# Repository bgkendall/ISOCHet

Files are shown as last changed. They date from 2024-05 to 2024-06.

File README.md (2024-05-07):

# ISOCHět

Macro pad based around an ISO Enter and using the CH552E MCU.

## Prerequisites

 * KiCad v7.0.9 or later
 * The following KiCad plugins are used for keyboard-specific components:
   * [marbastlib](https://github.com/ebastler/marbastlib) — footprints
   * [Keyswitch Kicad Library](https://github.com/kiswitch/kiswitch) —  3D models
 * [Josefin Sans](https://github.com/googlefonts/josefinsans) font — used for PCB text
 * FreeCAD v0.21.2 or later

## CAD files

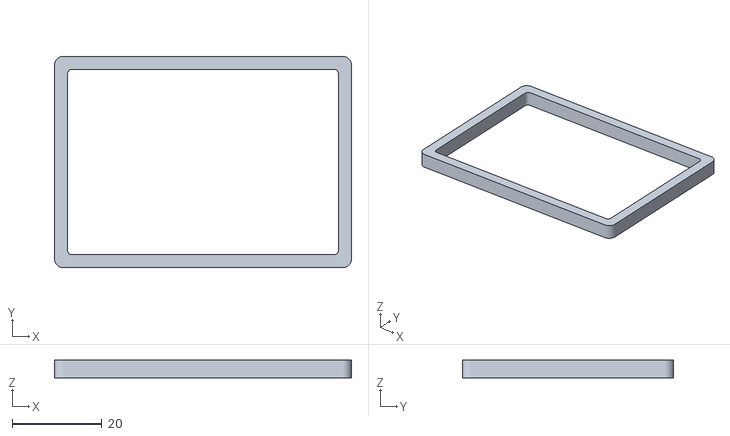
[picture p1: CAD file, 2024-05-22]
Case/ISOCHet-Accent.stl
66.2 x 47.1 x 4.00

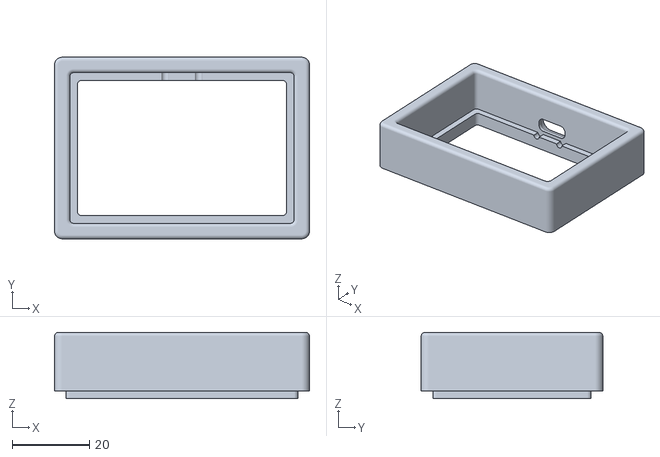
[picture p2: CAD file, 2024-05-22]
Case/ISOCHet-Body.stl
66.2 x 47.1 x 17.2

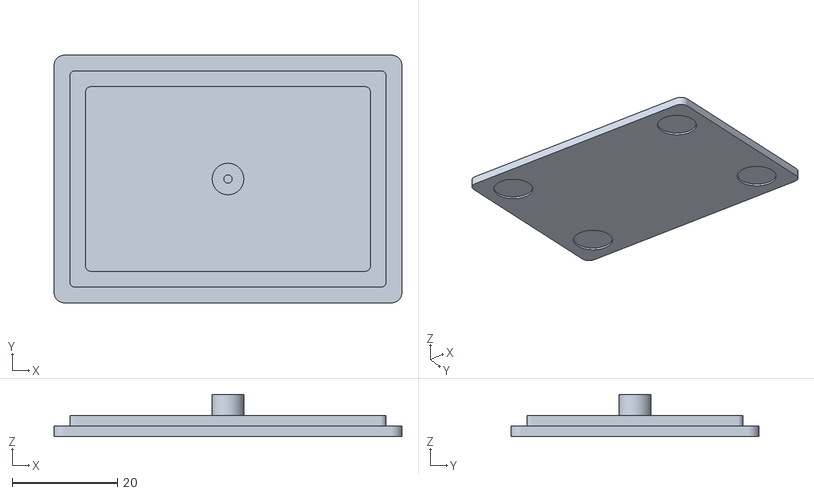
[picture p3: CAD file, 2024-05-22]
Case/ISOCHet-Base.stl
66.2 x 47.1 x 8.00

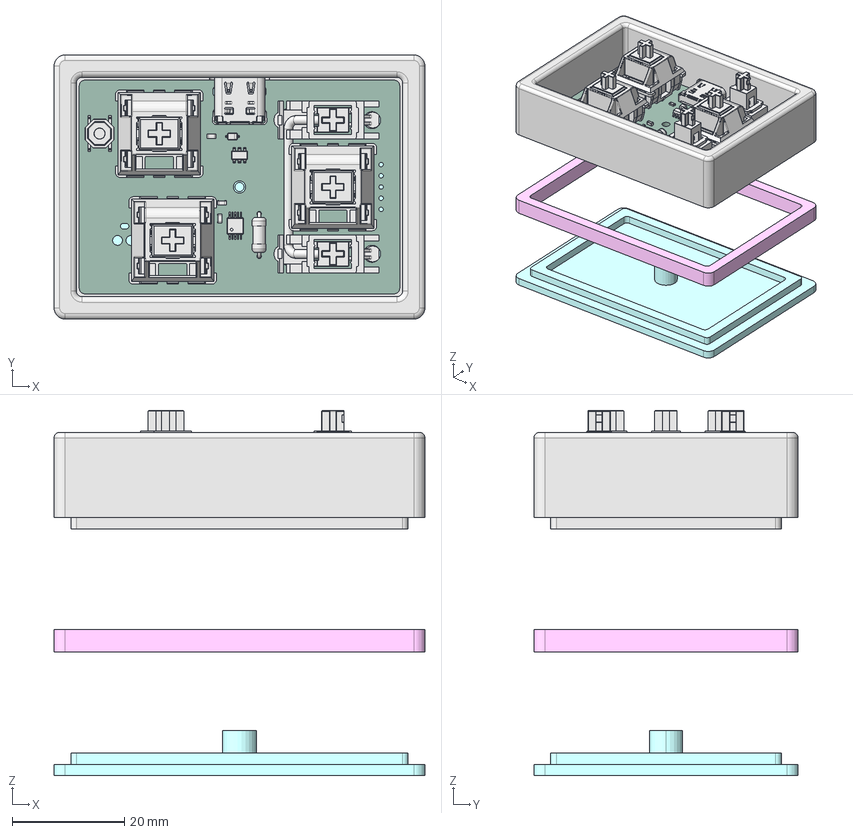
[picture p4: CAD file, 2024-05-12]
Case/ISOCHet.FCStd
66.2 x 47.1 x 65.1 mm
Base
Accent
ISOCHet PCB

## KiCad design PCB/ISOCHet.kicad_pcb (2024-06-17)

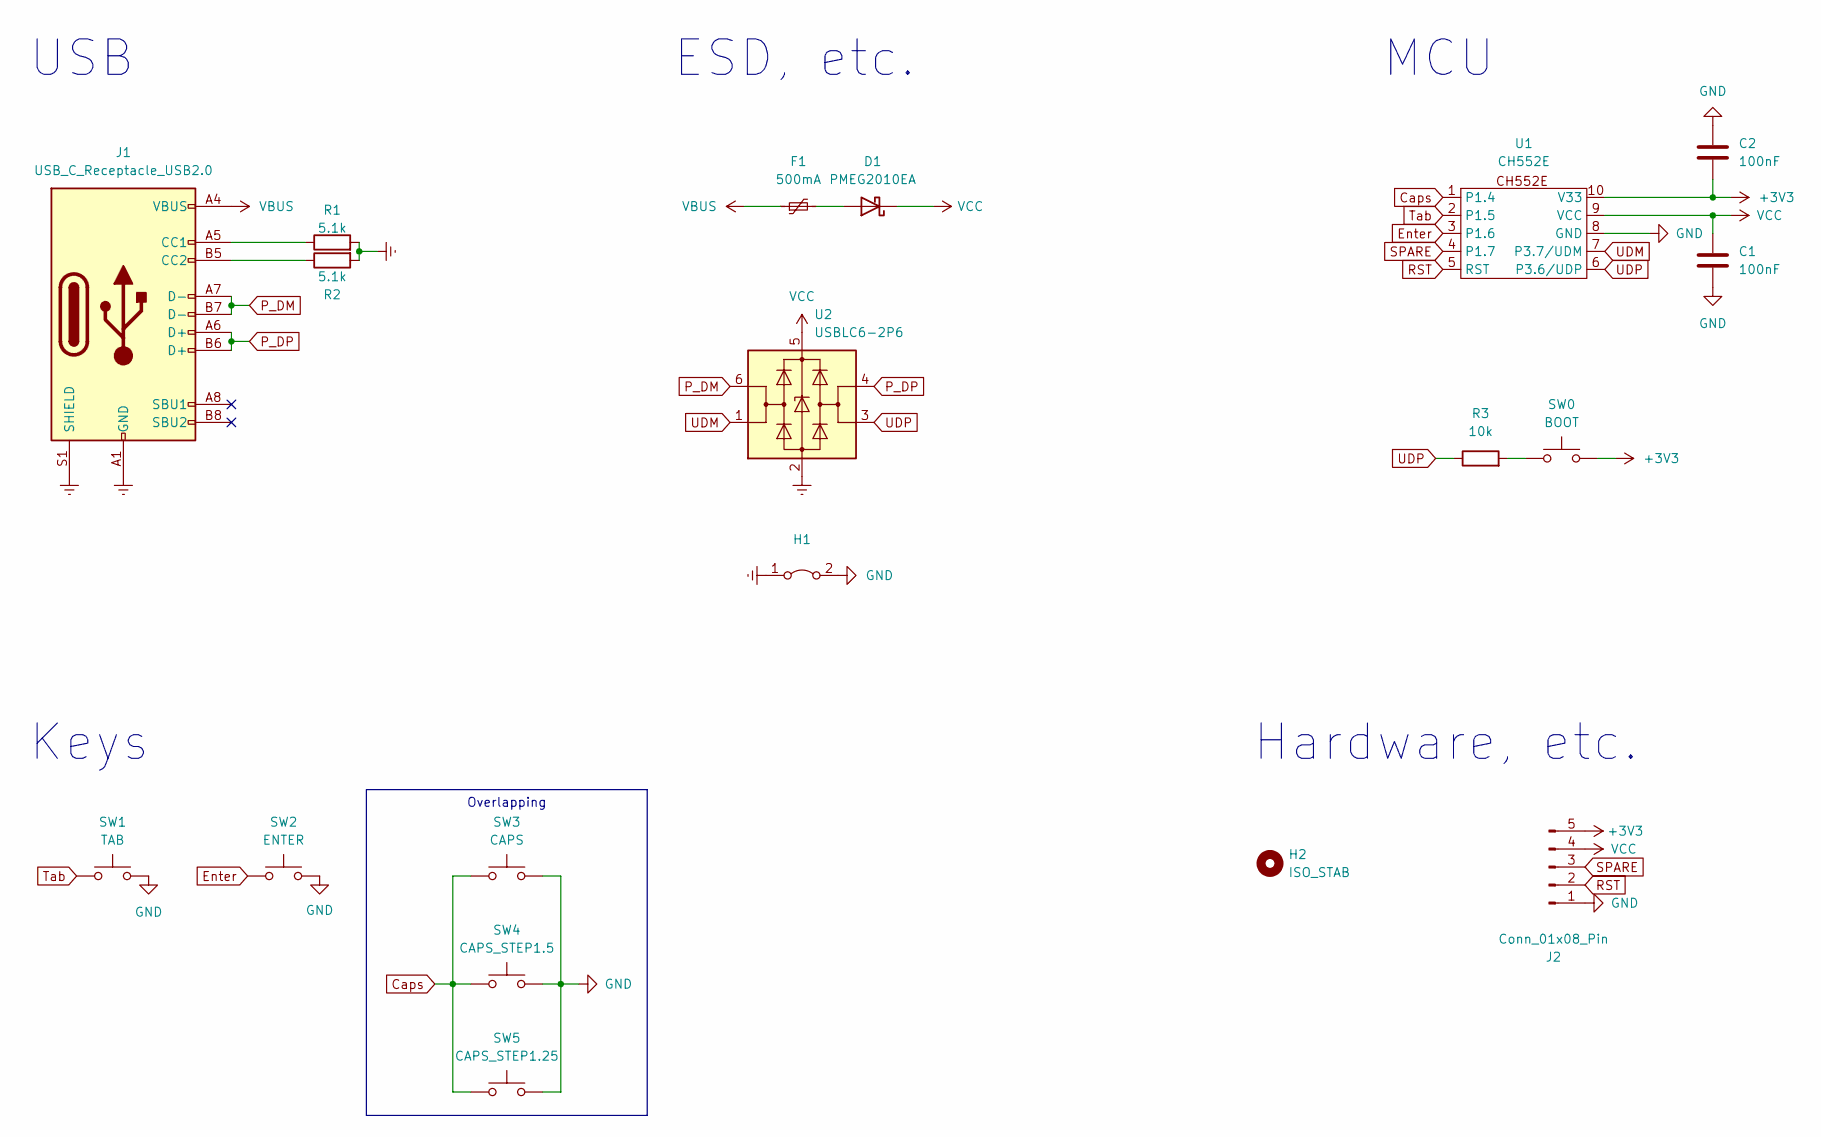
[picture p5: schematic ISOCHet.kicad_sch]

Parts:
C1, C2: 100nF; C_0603_1608Metric_Pad1.08x0.95mm_HandSolder; LCSC C66501
D1: PMEG2010EA; D_SOD-323_HandSoldering; LCSC C2837790
F1: 500mA; Fuse_0603_1608Metric_Pad1.05x0.95mm_HandSolder; LCSC C210357
H1: Mounting Hole/Isolated Ground Jumper; MountingHole_2.2mm_M2_DIN965_Pad_Isolated_Ground_Jumper
H2: ISO_STAB; STAB_MX_P_ISO-ROT
J1: USB_C_Receptacle_USB2.0; GSB1C211110DS1HR; LCSC C2840393
J2: Conn_01x08_Pin; PinHeader_1x05_P2.00mm_Vertical
R1, R2: 5.1k; R_0603_1608Metric_Pad0.98x0.95mm_HandSolder; LCSC C23186
R3: 10k; R_Combined_DIN0207_1608; LCSC C25804
SW0: BOOT; SW_SPST_SKQG_WithStem; LCSC C115351
SW1: TAB; SW_MX_1.5u
SW2: ENTER; SW_MX_1u
SW3: CAPS; SW_MX_1.75u
SW4: CAPS_STEP1.5; SW_MX_1.75u_STP_1.5
SW5: CAPS_STEP1.25; SW_MX_1.75u_STP_1.25
U1: CH552E; MSOP-10_3x3mm_P0.5mm; LCSC C967938
U2: USBLC6-2P6; SOT-23-6_Handsoldering; LCSC C2827654

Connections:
+3V3: C2.1, J2.5, SW0.2, U1.10 (V33)
Caps: SW3.1, SW4.1, SW5.1, U1.1 (P1.4)
Earth: H1.1 (A), J1.A1 (GND), J1.A12 (GND), J1.B1 (GND), J1.B12 (GND), J1.S1 (SHIELD), R1.2, R2.2, U2.2 (GND)
Enter: SW2.1, U1.3 (P1.6)
GND: C1.2, C2.2, H1.2 (B), J2.1, SW1.2, SW2.2, SW3.2, SW4.2, SW5.2, U1.8 (GND)
unnamed: D1.2 (A), F1.2
unnamed: J1.A5 (CC1), R1.1
unnamed: J1.B5 (CC2), R2.1
unnamed: R3.2, SW0.1
P_DM: J1.A7 (D-), J1.B7 (D-), U2.6 (I/O1)
P_DP: J1.A6 (D+), J1.B6 (D+), U2.4 (I/O2)
RST: J2.2, U1.5 (RST)
SPARE: J2.3, U1.4 (P1.7)
Tab: SW1.1, U1.2 (P1.5)
UDM: U1.7 (P3.7/UDM), U2.1 (I/O1)
UDP: R3.1, U1.6 (P3.6/UDP), U2.3 (I/O2)
VBUS: F1.1, J1.A4 (VBUS), J1.A9 (VBUS), J1.B4 (VBUS), J1.B9 (VBUS)
VCC: C1.1, D1.1 (K), J2.4, U1.9 (VCC), U2.5 (VBUS)

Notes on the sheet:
Overlapping
Keys
MCU
Hardware, etc.
ESD, etc.
USB

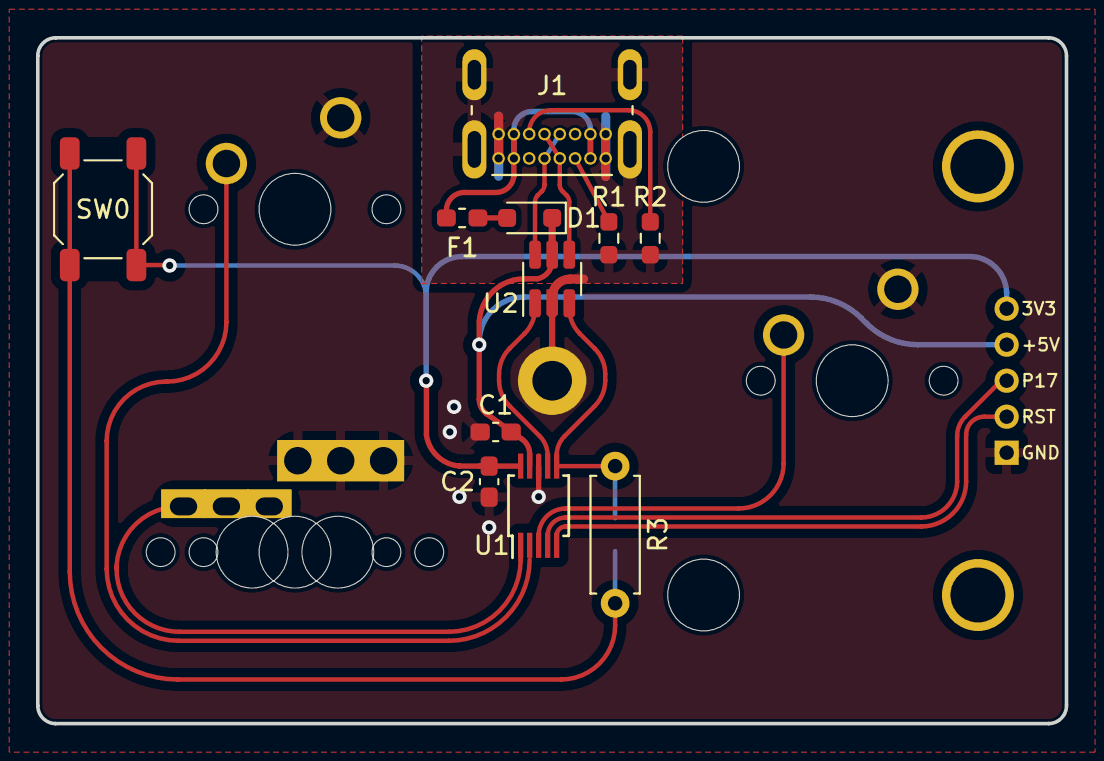
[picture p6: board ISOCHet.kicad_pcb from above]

Board: 2 copper layers, 57.1 x 38.1 mm, 19 parts (1 on the bottom side), 18 nets.

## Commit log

2024-04-16 Add first version of ISOCHet PCB
    [ISOCHet.kicad_pcb, ISOCHet.kicad_sch]
2024-04-16 Flip USB port to top side; add 3D models
    [ISOCHet.kicad_pcb, ISOCHet.kicad_sch]
2024-04-17 Add LSCC part numbers; add 3D models for MX switches and stabiliser
    [ISOCHet.kicad_pcb, ISOCHet.kicad_sch]
2024-04-17 Move OSHW logo to front, PCB name, etc. to back, and straighten a few traces
    [ISOCHet.kicad_pcb]
2024-04-17 Swap R1 and R2
    There’s more room for the via on the other side of the USB port.
    [ISOCHet.kicad_pcb]
2024-04-21 Rotate ISO stabiliser, improve STEP export
    [ISOCHet.kicad_pcb, ISOCHet.kicad_sch]
2024-04-21 Add first draft of case
    [ISOCHet.FCStd]
2024-04-21 Move CC resistors away from PCB edge
    [ISOCHet.kicad_pcb]
2024-04-21 Add cutouts for USB port solder
    [ISOCHet.FCStd]
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2024-04-21 Move components
    * Move decoupling capacitor C1 close to U1
    * Move U1 away from PCB edge
    * Align U1 with PCB centreline
    [ISOCHet.kicad_pcb, ISOCHet.kicad_sch]
2024-04-22 Use larger footprint for J2 header
    [ISOCHet.kicad_pcb, ISOCHet.kicad_sch]
2024-04-22 Update PCB model in case design
    [ISOCHet.FCStd]
2024-04-22 Tweak ESD routing
    [ISOCHet.kicad_pcb]
2024-04-23 Use Alps SKQG switch for BOOT, update LCSC part numbers, add DigiKey part numbers
    [ISOCHet.kicad_pcb, ISOCHet.kicad_sch]
2024-04-23 Change footprint for USB port
    USB C socket is now GSB1C211110DS1HR instead of GCT USB4085. Update routing with more filleting on 90° corners.
    [ISOCHet.kicad_pcb, ISOCHet.kicad_sch]
2024-04-23 Swap R1 and R2 (again)
    Also, make some routing prettier.
    [ISOCHet.kicad_pcb]
2024-04-25 Tidy up schematic
    [ISOCHet.kicad_sch]
2024-04-25 Refresh from schematic and tweak routing
    [ISOCHet.kicad_pcb]
2024-04-25 Rotated CH552 90° and rerouted accordingly
    [ISOCHet.kicad_pcb, ISOCHet.kicad_sch]
2024-04-26 Change routing of UDM and UDP
    Now leave U2 straight down rather than at 90°
    [ISOCHet.kicad_pcb]
2024-04-26 Tweak silkscreen lables for R3, C1 and C2
    [ISOCHet.kicad_pcb]
2024-04-26 Match width of pin-to-pin and thermal relief connections on Caps and J2
    [ISOCHet.kicad_pcb]
2024-04-26 Scooch order number
    [ISOCHet.kicad_pcb]
2024-04-26 Add courtyard for stabiliser screw pads
    [ISOCHet.kicad_pcb]
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2024-04-26 Tweak position of USB port, update PCB model in case design
    [ISOCHet.FCStd, ISOCHet.kicad_pcb]
2024-04-29 Create draft of version using CH552E
    [ISOCHet.kicad_pcb, ISOCHet.kicad_sch]
2024-05-02 Move all components to front
    USB data pins on port now line up with CH552E and do not need to crossover.
    R1 and R2 remain on back.
    Tweaked overlapping Caps Lock switch footprints to reduce DRC errors.
    Power tracks are now 0.3mm to match maximum width of CH552E pads.
    [ISOCHet.kicad_pcb, ISOCHet.kicad_sch]
2024-05-02 Use Josefin Sans for all mask text
    [ISOCHet.kicad_pcb]
2024-05-03 Prepare for production
    * Set fabrication flags.
    * Remove order number — cost is no different for a board this small.
    [ISOCHet.kicad_pcb]
2024-05-03 Isolate USD port ground from main PCB ground
    [ISOCHet.kicad_pcb]
2024-05-03 Move CC1 such that it is before U1, not after
    [ISOCHet.kicad_pcb]
2024-05-03 Round outside corners of keep-out areas
    KiCad only seems to round the inside corners, so some arcs on the GND net are added.
    [ISOCHet.kicad_pcb]
2024-05-03 Reroute UDP to Boot switch tracks
    [ISOCHet.kicad_pcb]
2024-05-03 Relocate and enlarge logo
    [ISOCHet.kicad_pcb]
2024-05-04 Switch USBLC6 (U2) to cheaper LCSC part number
    [ISOCHet.kicad_pcb, ISOCHet.kicad_sch]
2024-05-06 Update PCB 3D model
    [ISOCHet.FCStd]
2024-05-07 Recreate case design using length settings from spreadsheet
    [ISOCHet.FCStd]
2024-05-07 Add support for multiple standoffs
    Specifying a standoff X and/or Y offset in the spreadsheet will cause additional standoffs to be mirrored.
    Also, add appropriate labels to pads, pockets, etc.
    [ISOCHet.FCStd]
2024-05-08 Change R3 footprint to combined THT/SMD
    I realised I had a bunch of DIN0207 axial 10kΩ resistors, so switched the footprint for R3 to support *either* through hole *or* surface mount. I looked at doing the same for R1 and R2, but fitting a THT resistor while keeping the USB port ground plane relatively isolated proved to be too troublesome.
    Also fixed a DRC error on the VCC line into U1.
    [ISOCHet.kicad_pcb, ISOCHet.kicad_sch]
2024-05-10 Redo isolated ground
    Removed keep-out zones between parts of GND plane. Instead, moved USB port to “Earth” net and added a “jumper” between Earth and GND. The jumper is a simple custom footprint with three pairs of overlapping pads that replaces the previous GND-to-GND traces. New Earth zones have been added on the front and back cooper layers.
    R1 and R2 have been relocated to above and below the USB port’s pins rather than being left and right of the port. This simplifies their routing.
    [ISOCHet.kicad_pcb, ISOCHet.kicad_sch]
2024-05-10 Refresh PCB 3D model to check new R1 and R2 locations
    [ISOCHet.FCStd]
2024-05-10 Connect USBLC6 to isolated ground
    The USB ground (“Earth”) zone extends further down the board and the U2 ground pin connects to it and to H1 (the central mounting hole). H1 now has two pins and serves as the bridge between the two g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
    Also:
    * Switch U2 to more accurate USBLC6-2**SC6**
    * Remove all silkscreen from back except “R1” and “R2”
    [ISOCHet.kicad_pcb, ISOCHet.kicad_sch]
2024-05-10 Update U1 silkscreen position to match U2
    I.e., next to pin 1
    [ISOCHet.kicad_pcb]
2024-05-12 Change standoff hole to 1.6mm diameter to match M2 tap
    See https://www.aliexpress.us/item/3256801225285833.html
    [ISOCHet.FCStd]
2024-05-18 Make cosmetic tweaks to USB port ground plane
    [ISOCHet.kicad_pcb]
2024-05-18 Update CH552E symbol
    [ISOCHet.kicad_sch]
2024-05-21 Fix DRC error
    [ISOCHet.kicad_pcb]
2024-05-21 Generate Gerbers
    [ISOCHet-B_Cu.gbl, ISOCHet-B_Mask.gbs, ISOCHet-B_Paste.gbp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]
2024-05-22 Export STF models of case parts
    [ISOCHet-Accent.stl, ISOCHet-Base.stl, ISOCHet-Body.stl]
2024-06-08 Migrate project to KiCad v8
    [ISOCHet.kicad_pcb, ISOCHet.kicad_sch]
2024-06-08 Fix missing BOOT label; update PCB from v8 schematic
    [ISOCHet.kicad_pcb]
2024-06-08 Add ground stitching vias around MCU
    [ISOCHet.kicad_pcb]
2024-06-08 Add gap for ground plane between boot and switch traces
    [ISOCHet.kicad_pcb]
2024-06-08 Update PCB version to v1.1
    [ISOCHet.kicad_pcb]
2024-06-09 Decrease diameter of MX switch mounting pins
    The diameter has been decreased from 1.75mm to 1.6mm. This should improve the alignment of the switches given the plateless design of the case. However, some switches may no longer fit.
    [ISOCHet.kicad_pcb]
2024-06-09 Increase pad size on north side of Caps pin 1
    [ISOCHet.kicad_pcb]
2024-06-12 Increase gap between boot and switch traces
    [ISOCHet.kicad_pcb]
2024-06-17 Move R1 & R2 to top of board
    [ISOCHet.kicad_pcb, ISOCHet.kicad_sch]
2024-06-19 Fix project symbol library and CH552 symbol names
    [ISOCHet.kicad_sch]
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
